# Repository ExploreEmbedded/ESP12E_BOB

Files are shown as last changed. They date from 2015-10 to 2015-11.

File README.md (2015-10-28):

# ESP12E_BOB

The ESP8266 ESP12E Wifi Module is now more user friendly with the Explore ESP8266 Wi-Fi Module. It aptly fits on a breadboard 
with all pins taken out. The module goes into programming mode with a single reset switch. 
<a href = "https://www.exploreembedded.com/product/Explore%20ESP8266%20Wi-Fi%20Module">Click here</a> for more details.



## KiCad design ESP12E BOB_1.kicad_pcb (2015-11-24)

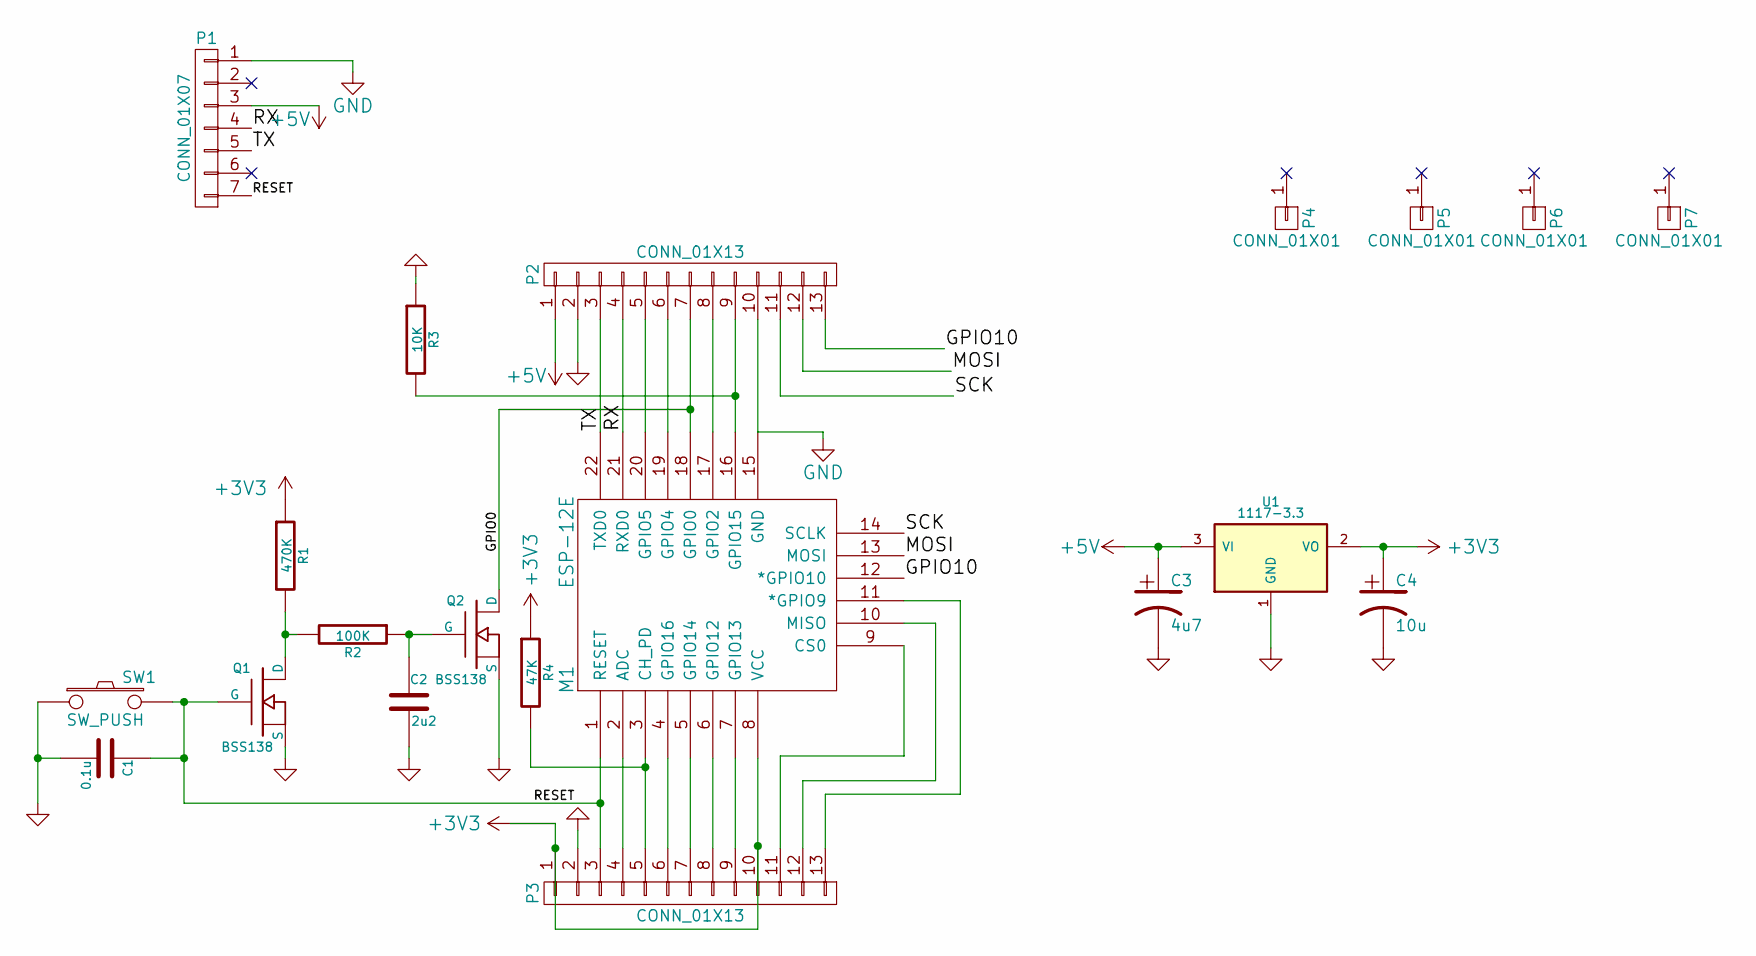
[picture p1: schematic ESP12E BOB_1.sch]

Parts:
C1: 0.1u; C_0805_HandSoldering
C2: 2u2; C_0805_HandSoldering
C3: 4u7; TantalC_SizeA_EIA-3216_Wave
C4: 10u; TantalC_SizeA_EIA-3216_Wave
M1: ESP-12E
P1: CONN_01X07
P2, P3: CONN_01X13
P4, P5, P6, P7: CONN_01X01
Q1, Q2: BSS138; SOT-23-GDS
R1: 470K; R_0805_HandSoldering
R2: 100K; R_0805_HandSoldering
R3: 10K; R_0805_HandSoldering
R4: 47K; R_0805_HandSoldering
SW1: SW_PUSH; PUSH_4x4_SMD
U1: 1117-3.3; SOT-223

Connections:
+3V3: C4.1, M1.8 (VCC), P3.1, P3.10, R1.1, R4.1, U1.2 (VO)
+5V: C3.1, P1.3, P2.1, U1.3 (VI)
/GPIO0: M1.18 (GPIO0), P2.7, Q2.D
/GPIO10: M1.12 (*GPIO10), P2.13
/MOSI: M1.13 (MOSI), P2.12
/RESET: C1.1, M1.1 (RESET), P1.7, P3.3, Q1.G, SW1.2
/RX: M1.21 (RXD0), P1.4, P2.4
/SCK: M1.14 (SCLK), P2.11
/TX: M1.22 (TXD0), P1.5, P2.3
GND: C1.2, C2.2, C3.2, C4.2, M1.15 (GND), P1.1, P2.2, P2.10, P3.2, Q1.S, Q2.S, R3.1, SW1.1, U1.1 (GND)
unnamed: C2.1, Q2.G, R2.1
unnamed: M1.2 (ADC), P3.4
unnamed: M1.3 (CH_PD), P3.5, R4.2
unnamed: M1.4 (GPIO16), P3.6
unnamed: M1.5 (GPIO14), P3.7
unnamed: M1.6 (GPIO12), P3.8
unnamed: M1.7 (GPIO13), P3.9
unnamed: M1.9 (CS0), P3.11
unnamed: M1.10 (MISO), P3.12
unnamed: M1.11 (*GPIO9), P3.13
unnamed: M1.16 (GPIO15), P2.9, R3.2
unnamed: M1.17 (GPIO2), P2.8
unnamed: M1.19 (GPIO4), P2.6
unnamed: M1.20 (GPIO5), P2.5
unnamed: Q1.D, R1.2, R2.2

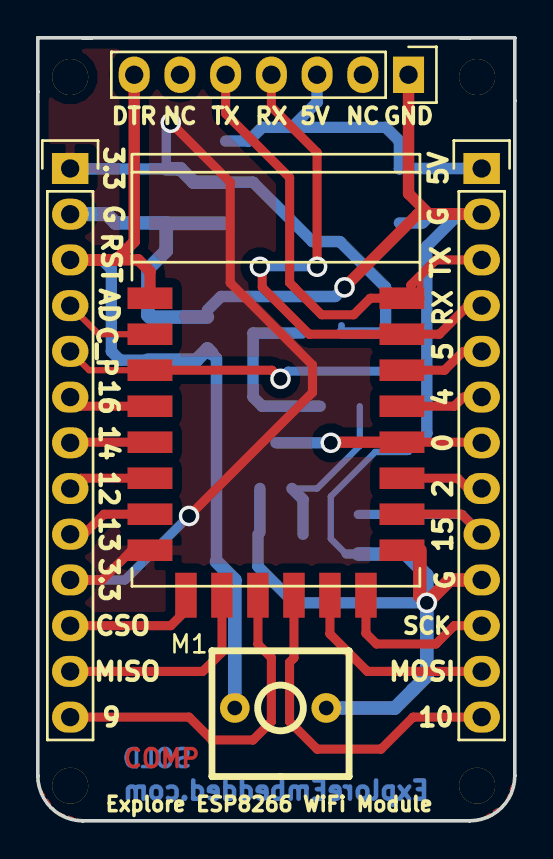
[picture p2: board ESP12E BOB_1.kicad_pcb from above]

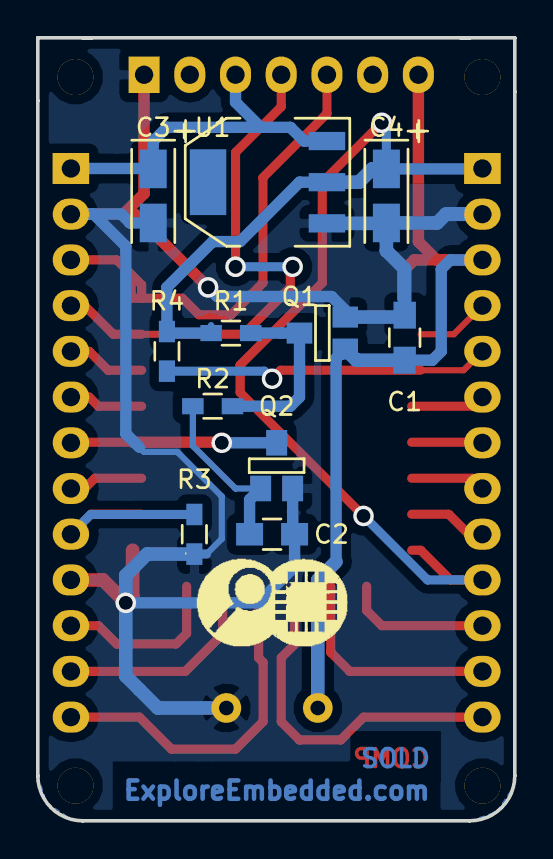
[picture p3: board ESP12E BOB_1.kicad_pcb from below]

Board: 2 copper layers, 26.5 x 43.5 mm, 21 parts (12 on the bottom side), 25 nets.

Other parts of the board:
LOGO: LOGO (2)

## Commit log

2015-06-17 test review
    [ESP12E BOB_1.kicad_pcb, ESP12E BOB_1.sch]
2015-07-13 ADDED NEW FILES
    [ESP12E BOB_1.kicad_pcb, ESP12E BOB_1.sch]
2015-07-25 Ident modified
    [ESP12E BOB_1-B_Cu.gbr, ESP12E BOB_1-B_Mask.gbr, ESP12E BOB_1-B_SilkS.gbr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]
2015-10-28 Changed legend and Connector
    [ESP12E BOB_1.kicad_pcb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]
2015-11-24 added corrected files
    [ESP12E BOB_1.kicad_pcb]
